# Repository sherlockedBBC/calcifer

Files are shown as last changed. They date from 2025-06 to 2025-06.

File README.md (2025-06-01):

# Calcifer LED-Lamp

This Repository contains information on the hard- and software of a LED-Lamp in the shape of Calcifer from the movie [Howl's Moving Castle](https://en.wikipedia.org/wiki/Howl%27s_Moving_Castle_(film)) by [Hayao Miyazaki](https://en.wikipedia.org/wiki/Hayao_Miyazaki).

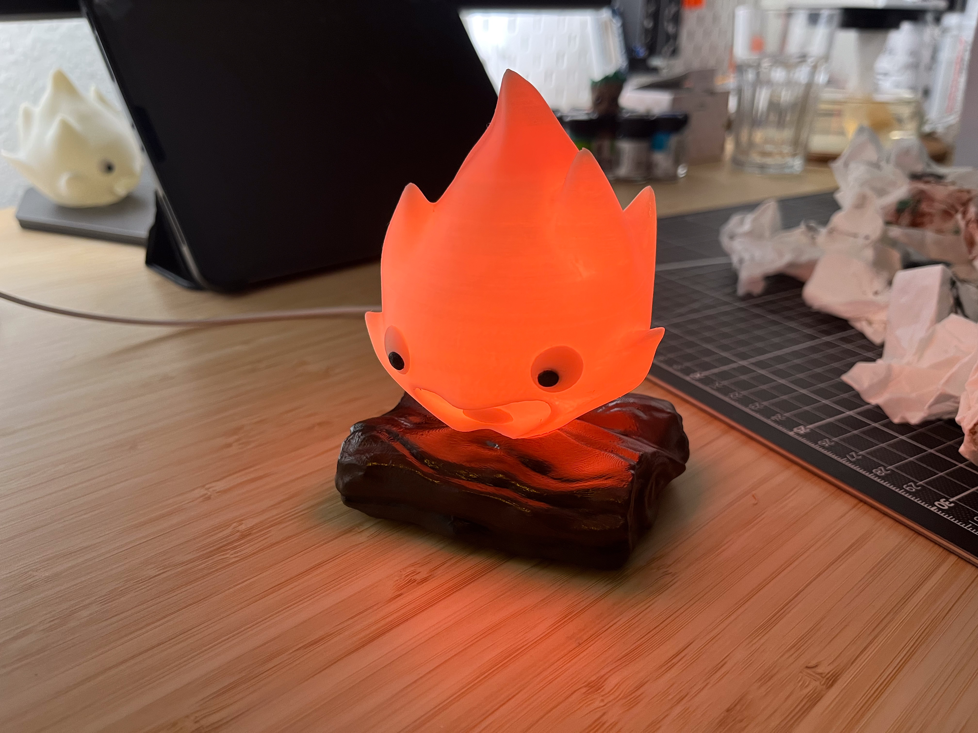
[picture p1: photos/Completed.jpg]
The completed Lamp


## Acknowledgements

The 3d print files are based on [CosmicNimbus's](https://makerworld.com/de/@CosmicNimbus) [Calcifer Lamp]('https://makerworld.com/de/models/551520-calcifer-lamp-bbl-led-kit-modified?from=search#profileId-470077') but were heavily modified to fit the requirements. My files can also be found on [printables](https://www.printables.com/model/1315251-calcifer-led-lamp).

During software development, I often used github copilot in VS Code to speed up development. I am not a software dev, but the code worked as intended so far. The libraries and frameworks used are listed in the ```platformio.ini```-file.

## Build

After 3d-printing all the parts, I used a hot-air station set at about 70 °C to soften up the eyes printed flat on the print bed. Once the desired curve has been archived, the eyes and the iris were glued on the main Calcifer body with epoxy.

Generic sticks of 8 WS2812B-LEDs each were soldered up and glued to the LED-Mount. A single WS2812B was glued on top. After that the LOLIN ESP32 S3 mini, the USB-C Jack, a 1000µF capacitor and a 3A fuse were soldered and mounted in the case. Three patches of copper tape soldered to the touch-inputs of the ESP32 are used as the user interface. The case is designed for heat-set inserts.

After sanding and a primer base coat, the paint job was applied.

The base was printed in white PLA. Calcifer was printed in glow-in-the-dark PLA.

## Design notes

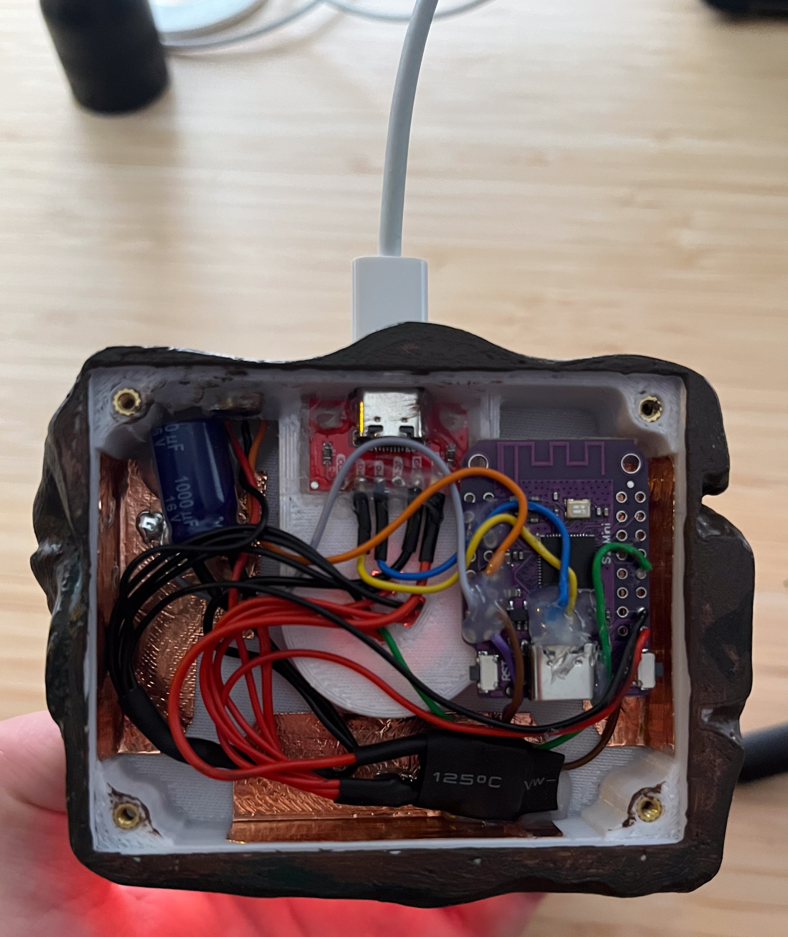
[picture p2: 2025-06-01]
photos/Inside.jpg

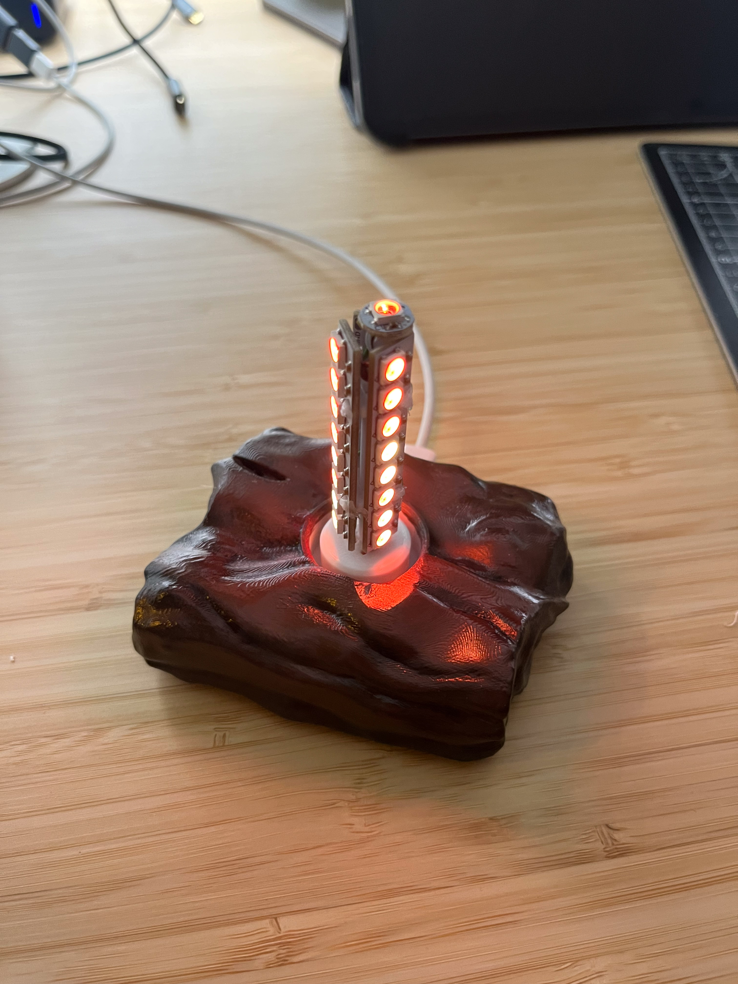
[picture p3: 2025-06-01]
photos/WithoutCalcifer.jpg

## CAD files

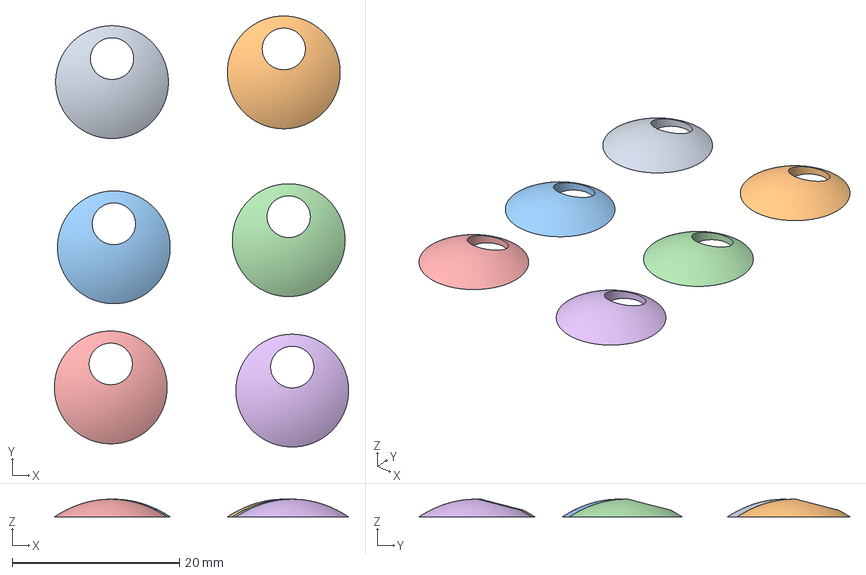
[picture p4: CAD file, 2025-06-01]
3d_print/Eyes_Flat.3mf
35.2 x 51.6 x 2.12 mm

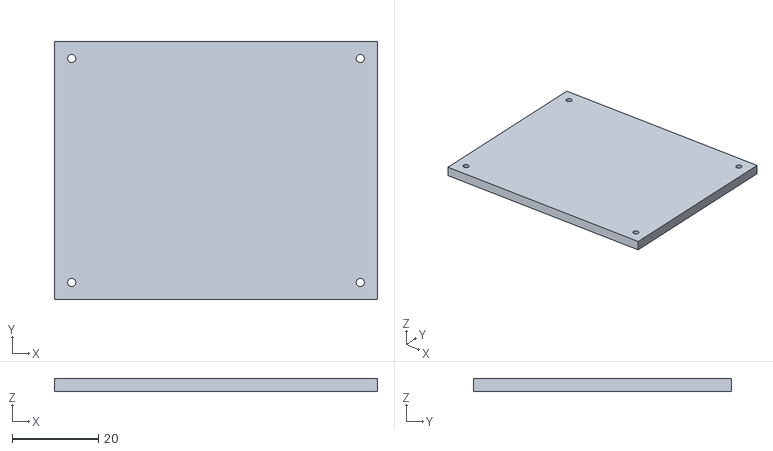
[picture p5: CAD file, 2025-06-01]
3d_print/Case_Bottom.stl
75.0 x 60.0 x 3.00

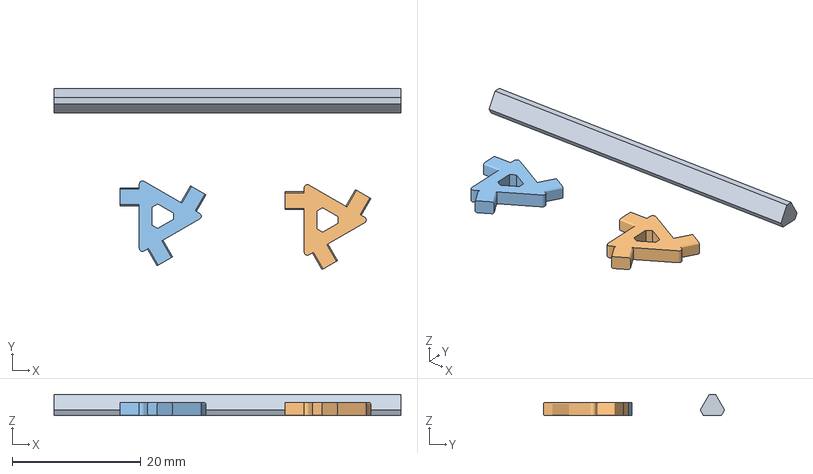
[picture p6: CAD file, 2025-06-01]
3d_print/LED-Mount.3mf
54.0 x 28.2 x 3.29 mm
K_rper_34
K_rper_35_(1)
K_rper_35

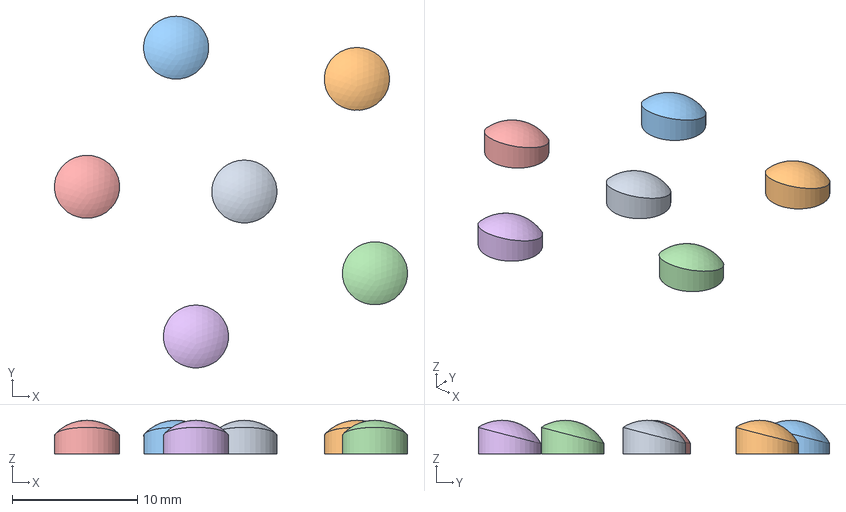
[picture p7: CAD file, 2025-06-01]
3d_print/Iris_Flat.3mf
28.2 x 28.1 x 2.68 mm

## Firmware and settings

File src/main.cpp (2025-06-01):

// ============================================================
// Calcifer Lamp
// 
// Author: Fabian Schmitt
//
// Device: ESP32-S2
// ============================================================
// Description:
// This code is for a Calcifer lamp using an ESP32-S2 microcontroller.
// ============================================================

#include <Arduino.h>
#include <TouchHandler.h>
#include <NeoPixelBus.h>
#include <NeoPixelAnimator.h>
#include <Smoothed.h>
#include <EEPROM.h>

// SETTINGS
#define LED_PIN    18                 // Pin number for the LED strip            
#define LED_NUM    25                 // Number of LEDs in the strip
#define ENABLE_AUTO_BRIGHTNESS true   // Enable or disable auto brightness adjustment

#define TOUCH_FRONT 14                // Pin number for front touch sensor
#define TOUCH_RIGHT 12                // Pin number for right side touch sensor
#define TOUCH_LEFT  13                // Pin number for left side touch sensor

#define LIGHTSENSOR_PIN 8             // Pin number for the TEMT6000 light sensor (if used)
#define LIGHTSENSOR_SMOOTHNESS 300    // Number of samples for smoothing the light sensor value
#define BRIGHTNESS_DEADBAND 0.05      // Deadband threshold for brightness changes

// Define EEPROM addresses for storing settings
#define EEPROM_SIZE 512
#define ADDR_CURRENT_BRIGHTNESS_STEP 0
#define ADDR_PREVIOUS_BRIGHTNESS_STEP 4
#define ADDR_CURRENT_BRIGHTNESS_VALUE 8
#define ADDR_PREVIOUS_BRIGHTNESS_VALUE 12
#define ADDR_CURRENT_ANIMATION_SETTING 16

// INSTANCES AND VARIABLES
const int touchPins[3] = {TOUCH_FRONT, TOUCH_LEFT, TOUCH_RIGHT};
const int numTouchPins = sizeof(touchPins) / sizeof(touchPins[0]);
TouchHandler touchHandler(touchPins, numTouchPins);

NeoPixelBus<NeoGrbFeature, NeoWs2812xMethod> strip(LED_NUM, LED_PIN);
NeoGamma<NeoGammaTableMethod> colorGamma;
NeoPixelAnimator animations(4, NEO_CENTISECONDS);


Smoothed <float> lightsensor;

float brightnessSteps[4] = {0.25, 0.5, 0.75, 1.0};
int currentBrightnessStep = 3;
int previousBrightnessStep = 2;
float currentBrightnessValue = 1.0; 
float previousBrightnessValue = 1.0;
int currentAnimantionSetting = 0; 
int currentPowerSetting = 1;
float previousEnvBrightnessValue = 1.0;

float brightnessValue = 1.0;
float powerCoeficient = 0.0;

RgbColor outputBuffer[LED_NUM] = {};

// FUNCTIONS
float getlux(float analogValue);
void showBuffer(RgbColor buffer[], int bufferSize);
void breathUpdate(AnimationParam param);
void softStart(AnimationParam param);
void softStop(AnimationParam param);
void brightnessFade(AnimationParam param);
void flameUpdate(AnimationParam param);
void restoreSettings();
void saveSettings();
void solidUpdate(AnimationParam param);
void nightFlameUpdate(AnimationParam param);

void setup() {

  pinMode(LED_PIN, OUTPUT);
  digitalWrite(LED_PIN, LOW);

  strip.Begin();
  strip.ClearTo(0);
  strip.Show();

  touchHandler.begin();
  
  Serial.begin(115200);
  delay(500);

  restoreSettings();

  lightsensor.begin(SMOOTHED_AVERAGE, LIGHTSENSOR_SMOOTHNESS);

  for(int i = 0; i < LED_NUM; i++) {
    outputBuffer[i] = RgbColor(0, 0, 0);
  }
}

void loop() {

  static unsigned long lastTouchedTime_Front = 0; // Tracks the last time a touch was detected
  static unsigned long lastTouchedTime_Left = 0; // Tracks the last time a touch was detected
  static unsigned long lastTouchedTime_Right = 0; // Tracks the last time a touch was detected
  const unsigned long debounceDelay = 350; // Debounce delay in milliseconds

  lightsensor.add(analogRead(LIGHTSENSOR_PIN));

  touchHandler.update();

  if (touchHandler.isTouched(0)) {
    unsigned long currentTime = millis();
    if (currentTime - lastTouchedTime_Front > debounceDelay) {
      lastTouchedTime_Front = currentTime; // Update the last touched time
      
      // Set Power
      if(currentPowerSetting == 0) {
        currentPowerSetting = 1;
        animations.StartAnimation(2, 75, softStart);
      } else {
        currentPowerSetting = 0;
        if(currentAnimantionSetting == 2) {
          animations.StopAnimation(1);
        }
        animations.StartAnimation(2, 75, softStop);
      }
    }
  }

  if (touchHandler.isTouched(1)) {
    unsigned long currentTime = millis();
    if (currentTime - lastTouchedTime_Left > debounceDelay) {
      lastTouchedTime_Left = currentTime; // Update the last touched time
      
      // Set Brightness
      #ifdef ENABLE_AUTO_BRIGHTNESS

      if(currentBrightnessStep == 4) {
        currentBrightnessStep = 0;
      } else {
        currentBrightnessStep++;
      }

      if(currentBrightnessStep == 0) {
        previousBrightnessStep = 3;
      } else {
        previousBrightnessStep = currentBrightnessStep - 1;
      }

      currentBrightnessValue = brightnessSteps[currentBrightnessStep];
      previousBrightnessValue = brightnessValue;

      if(currentBrightnessStep < 4) {
        animations.StartAnimation(3, 50, brightnessFade);
      }

      #elif

      if(currentBrightnessStep == 3) {
        currentBrightnessStep = 0;
      } else {
        currentBrightnessStep++;
      }

      currentBrightnessValue = brightnessSteps[currentBrightnessStep];
      previousBrightnessValue = brightnessSteps[previousBrightnessStep];
      
      animations.StartAnimation(3, 50, brightnessFade);

      #endif

      saveSettings(); // Save settings to EEPROM

    }
  }

  if (touchHandler.isTouched(2)) {
    unsigned long currentTime = millis();
    if (currentTime - lastTouchedTime_Right > debounceDelay) {
      lastTouchedTime_Right = currentTime; // Update the last touched time

      if(currentAnimantionSetting == 2) {
        currentAnimantionSetting = 0;
      } else {
        currentAnimantionSetting++;
      }

      switch (currentAnimantionSetting)
      {
      case 0: // Flame Animation
        animations.StartAnimation(1, 200, flameUpdate);
        break;
      case 1: // Solid Color
        animations.StartAnimation(1, 200, solidUpdate);
        break;
      case 2: // Night Flame Animation
        animations.StartAnimation(1, 200, nightFlameUpdate);
        break;
      }

      saveSettings(); // Save settings to EEPROM

    }
  }

  if(currentBrightnessStep == 4) {
    // automatic Brightness adjustment
    
    float lux = getlux(lightsensor.get());
    float newEnvBrightnessValue;

    if (lux >= 150) {
      newEnvBrightnessValue = 1.0;
    } else if (lux <= 25) {
      newEnvBrightnessValue = 0.2;
    } else {
      newEnvBrightnessValue = 0.2 + (log10(lux / 25.0) / log10(150.0 / 25.0)) * (1.0 - 0.2);
    }

    // Apply deadband filter
    if (abs(newEnvBrightnessValue - previousEnvBrightnessValue) > BRIGHTNESS_DEADBAND) {
      previousBrightnessValue = brightnessValue;
      currentBrightnessValue = newEnvBrightnessValue;
      previousEnvBrightnessValue = newEnvBrightnessValue;  // Update the previous value

      animations.StartAnimation(3, 100, brightnessFade);
    }
  }

  if(!animations.IsAnimationActive(1)) {

    switch (currentAnimantionSetting)
    {
    case 0: // Flame Animation
      animations.StartAnimation(1, 200, flameUpdate);
      break;
    case 1: // Solid Color
      animations.StartAnimation(1, 200, solidUpdate);
      break;
    case 2: // Night Flame Animation
      animations.StartAnimation(1, 200, nightFlameUpdate);
      break;
    }
  }

  animations.UpdateAnimations();
  showBuffer(outputBuffer, LED_NUM);
  delay(10);
  
}

void restoreSettings() {
  EEPROM.begin(EEPROM_SIZE);

  EEPROM.get(ADDR_CURRENT_BRIGHTNESS_STEP, currentBrightnessStep);
  EEPROM.get(ADDR_PREVIOUS_BRIGHTNESS_STEP, previousBrightnessStep);
  EEPROM.get(ADDR_CURRENT_BRIGHTNESS_VALUE, brightnessValue);
  EEPROM.get(ADDR_CURRENT_BRIGHTNESS_VALUE, currentBrightnessValue);
  EEPROM.get(ADDR_PREVIOUS_BRIGHTNESS_VALUE, previousBrightnessValue);
  EEPROM.get(ADDR_CURRENT_ANIMATION_SETTING, currentAnimantionSetting);

  animations.StartAnimation(3, 100, softStart);
}

void saveSettings() {
  EEPROM.put(ADDR_CURRENT_BRIGHTNESS_STEP, currentBrightnessStep);
  EEPROM.put(ADDR_PREVIOUS_BRIGHTNESS_STEP, previousBrightnessStep);
  EEPROM.put(ADDR_CURRENT_BRIGHTNESS_VALUE, currentBrightnessValue);
  EEPROM.put(ADDR_PREVIOUS_BRIGHTNESS_VALUE, previousBrightnessValue);
  EEPROM.put(ADDR_CURRENT_ANIMATION_SETTING, currentAnimantionSetting);
  EEPROM.commit(); // Save changes to EEPROM
}

void solidUpdate(AnimationParam param) {
  // Set the color to a solid value (e.g., red)
  RgbColor color = RgbColor(255, 64, 0); // Red color
  for (int i = 0; i < LED_NUM; i++) {
    outputBuffer[i] = color;
  }
}

void flameUpdate(AnimationParam param) {
  static RgbColor previousBuffer[LED_NUM]; // Store the previous frame's colors

  for (int i = 0; i < LED_NUM; i++) {
    // Random intensity for red and orange tones
    uint8_t redIntensity = random(120, 255);   // Red component (intense)
    uint8_t greenIntensity = random(0, 20);  // Green component (to create orange tones)
    uint8_t flicker = random(0, 140);          // Small flicker variation

    // Ensure values stay within valid range
    int adjustedRed = constrain(redIntensity + flicker, 0, 255);
    int adjustedGreen = constrain(greenIntensity + flicker, 0, 255);

    // Create the new color
    RgbColor newColor = RgbColor(adjustedRed, adjustedGreen, 0);

    // Blend the new color with the previous color for smooth transitions
    outputBuffer[i] = RgbColor::LinearBlend(previousBuffer[i], newColor, 0.23f); // Adjust blending factor (0.3) for smoothness

    // Store the current color for the next frame
    previousBuffer[i] = outputBuffer[i];
  }
}

void nightFlameUpdate(AnimationParam param) {

  static RgbColor previousBuffer[LED_NUM]; // Store the previous frame's colors

  for (int i = 0; i < LED_NUM; i++) {
    // Random intensity for red and orange tones
    uint8_t redIntensity = random(120, 255);   // Red component (intense)
    uint8_t greenIntensity = random(0, 20);  // Green component (to create orange tones)
    uint8_t flicker = random(0, 140);          // Small flicker variation

    // Ensure values stay within valid range
    int adjustedRed = constrain(redIntensity + flicker, 0, 255);
    int adjustedGreen = constrain(greenIntensity + flicker, 0, 255);

    // Create the new color
    RgbColor newColor = RgbColor(adjustedRed, adjustedGreen, 0);

    // Blend the new color with the previous color for smooth transitions
    outputBuffer[i] = RgbColor::LinearBlend(previousBuffer[i], newColor, 0.23f); // Adjust blending factor (0.3) for smoothness

    // Store the current color for the next frame
    previousBuffer[i] = outputBuffer[i];
  }

  outputBuffer[0] = RgbColor(255, 0, 50);
  outputBuffer[8] = RgbColor(255, 0, 50);
  outputBuffer[16] = RgbColor(255, 0, 50);

}

void breathUpdate(AnimationParam param) {

  // Adjust progress to create a ramp-up and ramp-down effect
  float progress = param.progress < 0.5 
                   ? NeoEase::QuadraticIn(param.progress * 2) // Ramp up
                   : NeoEase::QuadraticOut((1.0 - param.progress) * 2); // Ramp down

  // Set the color with the calculated brightness (e.g., red)
  RgbColor color = RgbColor::LinearBlend(RgbColor(255,0,0),RgbColor(255,128,0),progress);
  // in this case, just apply the color to first pixel
  for (int i = 0; i < LED_NUM; i++) {
    outputBuffer[i] = color;
  }

}

void brightnessFade(AnimationParam param) {

  float progress = NeoEase::CubicInOut(param.progress);

  brightnessValue = brightnessSteps[previousBrightnessStep] + (brightnessSteps[currentBrightnessStep] - brightnessSteps[previousBrightnessStep]) * progress;
  brightnessValue = previousBrightnessValue + (currentBrightnessValue - previousBrightnessValue) * progress;

}

void softStart(AnimationParam param) {

  powerCoeficient = NeoEase::CubicInOut(param.progress);

}

void softStop(AnimationParam param) {

  if(currentAnimantionSetting == 2) {
    for(int i = 0; i < LED_NUM; i++) {
      outputBuffer[i] = RgbColor::LinearBlend(outputBuffer[i], RgbColor(0,255,255), 0.4f); 
    }
  }

  powerCoeficient = NeoEase::CubicInOut(1.0 - param.progress);

}

void showBuffer(RgbColor buffer[], int bufferSize) {

  // Show the gamma-corrected buffer on the LED strip

  for (int i = 0; i < bufferSize; i++) {
    RgbColor bufferColor = RgbColor(
      buffer[i].R*brightnessValue*powerCoeficient, 
      buffer[i].G*brightnessValue*powerCoeficient, 
      buffer[i].B*brightnessValue*powerCoeficient
    );
    strip.SetPixelColor(i, colorGamma.Correct(bufferColor));
  }
  strip.Show();

}

float getlux(float analogValue) {

  // Copied from https://forum.arduino.cc/t/converting-temt6000-value-to-lux/180676/10
  float lux = analogValue * 0.9765625;  // 1000/1024

  return lux;
}
